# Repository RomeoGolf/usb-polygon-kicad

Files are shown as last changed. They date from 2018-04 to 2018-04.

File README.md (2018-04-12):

# USB-polygon (KiCAD)

Схема электрическая принципиальная и печатная плата отладочного устройства на базе микроконтроллера AT90USB162

## Краткое описание

Часть радиолюбительского проекта с целью создания простого устройства на микроконтроллере, имеющего возможность подключения к компьютеру по USB. Проект описан в цикле статей по адресу <http://romeogolf.github.io/tag/usb-polygon.html>.

Подробности использования платы в рамках проекта описаны в статьях цикла. Репозиторий содержит два коммита. Первый относится к статье [USB-polygon-2: Схема и плата](http://romeogolf.github.io/usb-polygon-2.html), второй --- к статье [USB-polygon-20: Мышиный энкодер](http://romeogolf.github.io/usb-polygon-20.html). Во втором коммите добавлены элементы в схему электрическую принципиальную без внесения их в печать, так как доработка выполнялась навесным монтажом, перемычками.

Плата в KiCAD
Вид со стороны контроллера
Вид со стороны навесных элементов

[pre_pcb]: http://romeogolf.github.io/images/usb-polygon/02/preview/face-cad-small.png "Плата"
[pre_cpu]: http://romeogolf.github.io/images/usb-polygon/02/preview/cpu-small.jpg "Вид со стороны контроллера"
[pre_led]: http://romeogolf.github.io/images/usb-polygon/02/preview/led-small.jpg "Вид со стороны навесных элементов"

### Остальные части проекта:

* программа на C для микроконтроллера устройства [(ссылка)](https://github.com/RomeoGolf/usb-polygon-embedded)
* программа на C++ для взаимодействия с устройством со стороны ПК [(ссылка)](https://github.com/RomeoGolf/usb-polygon-cpp)
* программа на С++ для опроса одного из "файлов" на устройстве в непрерывном режиме (с отключением буферизации данных на ПК) [(ссылка)](https://github.com/RomeoGolf/usb-polygon-read-loop)
* программа на С++ для подготовки кадров "циферблата", отображаемого на ЖК-экране [(ссылка)](https://github.com/RomeoGolf/usb-polygon-makedial)

## Начало работы

### Зависимости

Для просмотра и внесения изменений необходим [KiCAD](http://kicad-pcb.org/).

### Получение

Для получения копии репозитория следует воспользоваться кнопкой "Clone or download" на [странице репозитория](https://github.com/RomeoGolf/usb-polygon-kicad).

При отсутствии git можно нажать кнопку "Download ZIP" и получить последнюю версию без истории коммитов.

При наличии git можно скопировать URL https://github.com/RomeoGolf/usb-polygon-kicad.git и использовать его в команде

~~~~
git clone https://github.com/RomeoGolf/usb-polygon-kicad.git
~~~~

в командной строке (git bash, например, в зависимости от ОС и настроек).

Далее можно открыть в KiCad файл "polygon.pro" и работать с проектом.

## Развитие проекта

Дальнейшее развитие проекта не предполагается, так как цель достигнута.

## Лицензия

This project is licensed under the MIT License - see the [License.txt](License.txt) file for details

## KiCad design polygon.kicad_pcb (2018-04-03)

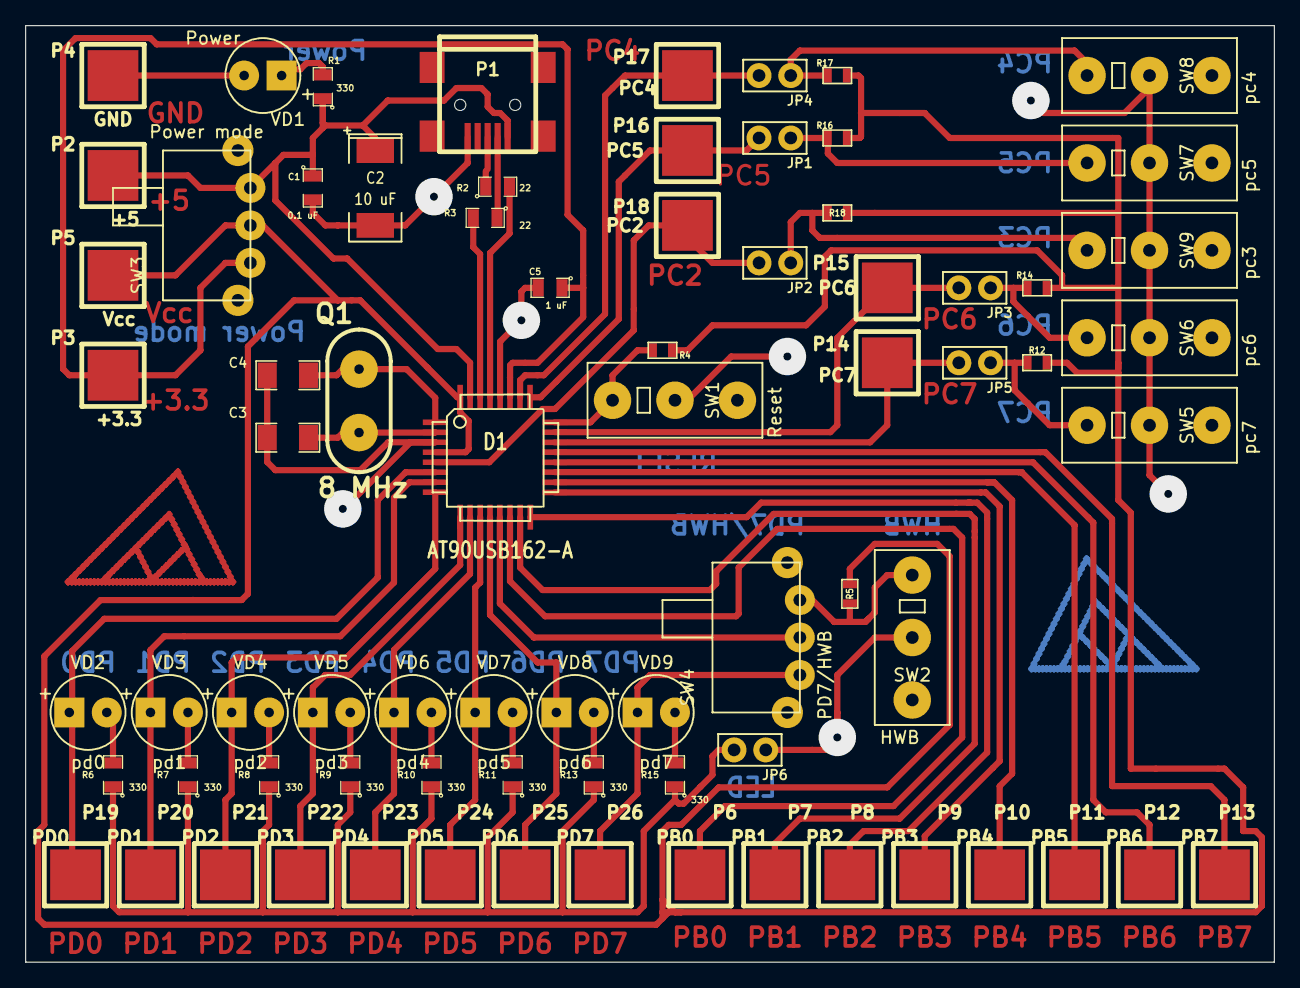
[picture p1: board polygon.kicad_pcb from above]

Board: 2 copper layers, 100.0 x 75.0 mm, 75 parts (0 on the bottom side), 49 nets.

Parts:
C1: 0.1 uF; SM0805
C2: 10 uF; SM2512
C3, C4: 22 pF; SM1206
C5: 1 uF; SM0805
D1: AT90USB162-A; TQFP32
JP1: pc5; JUMPER
JP2: pc3; JUMPER
JP3: pc6; JUMPER
JP4: pc4; JUMPER
JP5: pc7; JUMPER
JP6: LED; JUMPER
P1: USB-MINI-B; USB__MINI_B
P2: +5; 1PIN_SMD
P3: +3.3; 1PIN_SMD
P4: GND; 1PIN_SMD
P5: Vcc; 1PIN_SMD
P6: PB0; 1PIN_SMD
P7: PB1; 1PIN_SMD
P8: PB2; 1PIN_SMD
P9: PB3; 1PIN_SMD
P10: PB4; 1PIN_SMD
P11: PB5; 1PIN_SMD
P12: PB6; 1PIN_SMD
P13: PB7; 1PIN_SMD
P14: PC7; 1PIN_SMD
P15: PC6; 1PIN_SMD
P16: PC5; 1PIN_SMD
P17: PC4; 1PIN_SMD
P18: PC2; 1PIN_SMD
P19: PD0; 1PIN_SMD
P20: PD1; 1PIN_SMD
P21: PD2; 1PIN_SMD
P22: PD3; 1PIN_SMD
P23: PD4; 1PIN_SMD
P24: PD5; 1PIN_SMD
P25: PD6; 1PIN_SMD
P26: PD7; 1PIN_SMD
Q1: 8 MHz; QUARTZ_5mm
R1, R6, R7, R8, R9, R10, R11, R13, R15: 330; SM0805
R2, R3: 22; SM0805
R4, R5, R12, R14, R16, R17, R18: 10 k; SM0603
SW1: Reset; SW_MOUSE
SW2: HWB; SW_MOUSE
SW3: Power mode; switch3
SW4: PD7/HWB; switch3
SW5: pc7; SW_MOUSE
SW6: pc6; SW_MOUSE
SW7: pc5; SW_MOUSE
SW8: pc4; SW_MOUSE
SW9: pc3; SW_MOUSE
VD1: Power; LED_3MM
VD2: pd0; LED_3MM
VD3: pd1; LED_3MM
VD4: pd2; LED_3MM
VD5: pd3; LED_3MM
VD6: pd4; LED_3MM
VD7: pd5; LED_3MM
VD8: pd6; LED_3MM
VD9: pd7; LED_3MM

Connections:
+3.3V: C5.1, D1.27, P3.1, SW3.3
+5V: C1.1, C2.1, D1.31, P1.1, P2.1, R1.1, SW3.1
GND: C1.2, C2.2, C3.1, C4.1, C5.2, D1.3, D1.28, JP6.2, P1.5, P4.1, SW1.3, SW2.3, SW5.3, SW6.3, SW7.3, SW8.3, SW9.3, VD1.2
unnamed: JP3.2, R14.2, SW6.2
unnamed: D1.15, P7.1
unnamed: D1.14, P6.1
unnamed: D1.20, P12.1
unnamed: D1.17, P9.1
unnamed: D1.18, P10.1
unnamed: D1.19, P11.1
unnamed: JP2.2, R18.2, SW9.2
unnamed: JP4.2, R17.2, SW8.2
unnamed: JP1.2, R16.2, SW7.2
unnamed: JP5.2, R12.2, SW5.2
unnamed: D1.22, JP5.1, P14.1
unnamed: D1.26, JP4.1, P17.1
unnamed: D1.25, JP1.1, P16.1
unnamed: D1.23, JP3.1, P15.1
unnamed: D1.21, P13.1
unnamed: D1.16, P8.1
unnamed: D1.8, P21.1, VD4.1
unnamed: D1.6, P19.1, VD2.1
unnamed: D1.7, P20.1, VD3.1
unnamed: D1.9, P22.1, VD5.1
unnamed: D1.13, SW4.2
unnamed: R5.1, SW2.2, SW4.1
unnamed: D1.5, JP2.1, P18.1
unnamed: P1.3, R2.1
unnamed: P1.2, R3.1
unnamed: R1.2, VD1.1
unnamed: D1.24, R4.1, SW1.2
unnamed: R15.2, VD9.2
unnamed: P26.1, SW4.3, VD9.1
unnamed: R13.2, VD8.2
unnamed: D1.12, P25.1, VD8.1
unnamed: R11.2, VD7.2
unnamed: D1.11, P24.1, VD7.1
unnamed: R10.2, VD6.2
unnamed: D1.10, P23.1, VD6.1
unnamed: R9.2, VD5.2
unnamed: R8.2, VD4.2
unnamed: R7.2, VD3.2
unnamed: R6.2, VD2.2
unnamed: D1.30, R3.2
unnamed: C3.2, D1.2, Q1.1
unnamed: D1.29, R2.2
unnamed: JP6.1, R6.1, R7.1, R8.1, R9.1, R10.1, R11.1, R13.1, R15.1
unnamed: C4.2, D1.1, Q1.2
VCC: D1.4, D1.32, P5.1, R4.2, R5.2, R12.1, R14.1, R16.1, R17.1, R18.1, SW3.2

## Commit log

2018-04-03 Initial commit
    На самом деле, завершенная схема и плата.
    [polygon.kicad_pcb, polygon.sch]
2018-04-03 Добавление энкодера в сему электрическую принципиальную
    без правки разводки платы, новые элементы только на схеме
    [polygon.sch]
2018-04-07 Добавил файл лицензии MIT
